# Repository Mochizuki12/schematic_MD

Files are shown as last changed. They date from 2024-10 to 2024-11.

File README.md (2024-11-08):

# schematic_MD
### 2chモータドライバのプロトタイプ<br>
[回路の仕様](https://github.com/Mochizuki12/schematic_MD/blob/v0.1.0/documents/MDdocument.pdf)<br>
[回路図](https://github.com/Mochizuki12/schematic_MD/blob/v0.1.0/documents/MD_schematics.pdf)<br>
[PCB](https://github.com/Mochizuki12/schematic_MD/blob/v0.1.0/documents/pcb.pdf)<br>

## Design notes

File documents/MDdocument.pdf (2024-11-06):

MDプロトタイプ１ | 1

# MDプロトタイプ１

最終版との差異
モータ用電源 13V~24V

ゲート電圧がモータ用電源電圧に依存

12V降圧レギュレータに変更。アクチュエータ側は最低13V必要

## 部品(IC)

部品名 | 型番 | 備考 | URL
ゲートドライバ | ADuM3224 | ADuM3223とピン 互換あり オーバーラップ保 護機能がないため 使用中止
ゲートドライバ | UCC21520DWR | オーバーラップ保 護あり ドライブ側の UVLOが高く (8V)、現状のコン デンサでは充電が 間に合わない可能 性あり プロトタイプで採 用 | https://jlcpcb.com/partdetail/TexasInstruments-UCC21520DWR/C601651 (https://jlcpcb.com/partdetail/TexasInstruments-UCC21520DWR/C601651)
ゲートドライバ | UCC21520ADWR | オーバーラップ保 護あり ドライブ側の UVLOが低い(5V)
マイコン | STM32F405 | ユニバーサルプロ グラムにより提供
CANトランシーバ | MAX3051 | | https://jlcpcb.com/partdetail/113237-MAX3051EKAT/C112005 (https://jlcpcb.com/partdetail/113237-MAX3051EKAT/C112005)
3端子レギュレータ | L78M05ABDT-TR | 5V降圧 | https://jlcpcb.com/partdetail/Stmicroelectronics-L78M05ABDTTR/C58069 (https://jlcpcb.com/partdetail/Stmicroelectronics-L78M05ABDTTR/C58069)
3端子レギュレータ | XC6206P332MR-G | 3.3V降圧 | https://jlcpcb.com/partdetail/TorexSemicon-XC6206P332MRG/C5446 (https://jlcpcb.com/partdetail/TorexSemicon-XC6206P332MRG/C5446)
3端子レギュレータ | NJM2396 | 12V降圧 | https://akizukidenshi.com/catalog/g/g109264/
ロジックIC | 74HC04D | NOTゲート | https://jlcpcb.com/partdetail/Nexperia-74HC04D653/C5590 (https://jlcpcb.com/partdetail/Nexperia-74HC04D653/C5590)

### 部品(受動部品)

部品名 | 型番 | 備考 | URL

ゲート抵抗10Ω | 選定基準は下記 に記載 | https://jlcpcb.com/partdetail/18103-0805W8F100JT5E/C17415 (https://jlcpcb.com/partdetail/18103-0805W8F100JT5E/C17415)
ブートストラッ プ抵抗100mΩ | | https://jlcpcb.com/partdetail/26077-1206W4F100LT5E/C25334 (https://jlcpcb.com/partdetail/26077-1206W4F100LT5E/C25334)
120Ω抵抗 | CAN 終端抵抗 | https://jlcpcb.com/partdetail/23514-0603WAF1200T5E/C22787 (https://jlcpcb.com/partdetail/23514-0603WAF1200T5E/C22787)
330Ω抵抗 | LED用 | https://jlcpcb.com/partdetail/23865-0603WAF3300T5E/C23138 (https://jlcpcb.com/partdetail/23865-0603WAF3300T5E/C23138)
680Ω抵抗 | LED用 | https://jlcpcb.com/partdetail/23955-0603WAF6800T5E/C23228 (https://jlcpcb.com/partdetail/23955-0603WAF6800T5E/C23228)
2kΩ抵抗 | LED用 | https://jlcpcb.com/partdetail/23702-0603WAF2001T5E/C22975 (https://jlcpcb.com/partdetail/23702-0603WAF2001T5E/C22975)
3.6kΩ抵抗 | LED用 | https://jlcpcb.com/partdetail/23707-0603WAF3601T5E/C22980 (https://jlcpcb.com/partdetail/23707-0603WAF3601T5E/C22980)
電力消費用10k 抵抗 | コンデンサの電 荷抜き | https://jlcpcb.com/partdetail/18590-1206W4F1002T5E/C17902 (https://jlcpcb.com/partdetail/18590-1206W4F1002T5E/C17902)
プルダウン用 10k抵抗 | | https://jlcpcb.com/partdetail/26487-0402WGF1002TCE/C25744 (https://jlcpcb.com/partdetail/26487-0402WGF1002TCE/C25744)
プルダウン用 20k抵抗 | | https://jlcpcb.com/partdetail/26508-0402WGF2002TCE/C25765 (https://jlcpcb.com/partdetail/26508-0402WGF2002TCE/C25765)
インジケータ LED Vf=1.7@5mA | 赤色 | https://jlcpcb.com/partdetail/Hubei_KentoElec-KT0603R/C2286 (https://jlcpcb.com/partdetail/Hubei_KentoElec-KT0603R/C2286)
インジケータ LED Vf=1.875@5mA | 黄色 | https://jlcpcb.com/partdetail/Hubei_KentoElec-KT0805Y/C2296 (https://jlcpcb.com/partdetail/Hubei_KentoElec-KT0805Y/C2296)
バイパス用コン デンサ0.1uF 12V, 5V系統 | | https://jlcpcb.com/partdetail/Yageo-CC0603KRX7R9BB104/C14663 (https://jlcpcb.com/partdetail/Yageo-CC0603KRX7R9BB104/C14663)
バイパス用コン デンサ0.1uF 3.3V系統 | | https://jlcpcb.com/partdetail/1877-CL05B104KO5NNNC/C1525 (https://jlcpcb.com/partdetail/1877-CL05B104KO5NNNC/C1525)
バイパス用コン デンサ4.7uF | | https://jlcpcb.com/partdetail/20375-CL10A475KO8NNNC/C19666 (https://jlcpcb.com/partdetail/20375-CL10A475KO8NNNC/C19666)
バイパス用コン デンサ2.2uF | | https://jlcpcb.com/partdetail/24366-CL10A225KO8NNNC/C23630 (https://jlcpcb.com/partdetail/24366-CL10A225KO8NNNC/C23630)
バイパス用コン デンサ1uF | | https://jlcpcb.com/partdetail/16531-CL10A105KB8NNNC/C15849 (https://jlcpcb.com/partdetail/16531-CL10A105KB8NNNC/C15849)
バイパス用コン デンサ1nF | | https://jlcpcb.com/partdetail/1940-CL10B102KB8NNNC/C1588 (https://jlcpcb.com/partdetail/1875-0402B102K500NT/C1523)
バイパス用コン デンサ22nF | | https://jlcpcb.com/partdetail/1884-0402B223K500NT/C1532 (https://jlcpcb.com/partdetail/1884-0402B223K500NT/C1532)
バイパス用コン デンサ0.47uF | | https://jlcpcb.com/partdetail/14623-CL21B474KBFNNNE/C13967 (https://jlcpcb.com/partdetail/14623-CL21B474KBFNNNE/C13967)
フェライトビー ズ 600Ω@100MHz | STM32アナログ 電源フィルタ用 | https://jlcpcb.com/partdetail/Sunlord-GZ2012D601TF/C1017 (https://jlcpcb.com/partdetail/Sunlord-GZ2012D601TF/C1017)

ショットキーバ リアダイオード | 超低IRタイプ Extend品 | https://jlcpcb.com/partdetail/RohmSemicon-RB168MM60TR/C509937 (https://jlcpcb.com/partdetail/RohmSemicon-RB168MM60TR/C509937)
Nch MOSFET | 標準アセンブリ 品 | https://jlcpcb.com/partdetail/VishayIntertech-SQJ886EPT1_GE3/C727822 (https://jlcpcb.com/partdetail/VishayIntertech-SQJ886EPT1_GE3/C727822)
Nch MOSFET | Economyでも可 能 Extend品 | https://jlcpcb.com/partdetail/VishayIntertech-SIR182DP_T1RE3/C467943 (https://jlcpcb.com/partdetail/VishayIntertech-SIR182DP_T1RE3/C467943)
ゲートキャパシ タ10uF | Extend品 | https://jlcpcb.com/partdetail/-12103C106K4T2A/C597571
フィルタ用抵抗 51Ω | PWM入力ロー パスフィルタを 構成 | https://jlcpcb.com/partdetail/23924-0603WAF510JT5E/C23197 (https://jlcpcb.com/partdetail/23924-0603WAF510JT5E/C23197)
フィルタ用コン デンサ33pF | PWM入力ロー パスフィルタを 構成 | https://jlcpcb.com/partdetail/2015-CL10C330JB8NNNC/C1663 (https://jlcpcb.com/partdetail/2015-CL10C330JB8NNNC/C1663)
LSE用水晶振動 子32.768kHz | STM用 | https://jlcpcb.com/partdetail/SeikoEpson-Q13FC13500004/C32346 (https://jlcpcb.com/partdetail/SeikoEpson-Q13FC13500004/C32346)
LSE用負荷容量 20pF | 32kHz水晶振動 子用 | https://jlcpcb.com/partdetail/1906-0402CG200J500NT/C1554 (https://jlcpcb.com/partdetail/1906-0402CG200J500NT/C1554)
HSE用水晶振動 子25MHz | STM用 | https://jlcpcb.com/partdetail/Yxc_CrystalOscillators-X322516MLB4SI/C13738 (https://jlcpcb.com/partdetail/Yxc_CrystalOscillators-X322525MOB4SI/C9006)
HSE用負荷容量 18pF | 25MHz用 | https://jlcpcb.com/partdetail/1999-CL10C180JB8NNNC/C1647 (https://jlcpcb.com/partdetail/1901-0402CG180J500NT/C1549)
リセットスイッ チ | 試験運用 | https://jlcpcb.com/partdetail/XkbConnection-TS_1187A_B_AB/C318884 (https://jlcpcb.com/partdetail/XkbConnection-TS_1187A_B_AB/C318884)
DIP スイッチ 4P | 秋月で購入 | https://akizukidenshi.com/catalog/g/g108929/

### 秋月購入品

部品名 | URL
ゲート電源用12V降圧 | https://akizukidenshi.com/catalog/g/g116614
バイパスコンデンサ22uF | https://akizukidenshi.com/catalog/g/g117899/
12V電源用電解コンデンサ | https://akizukidenshi.com/catalog/g/g102724/
5V, 3.3V電源用電解コンデンサ | https://akizukidenshi.com/catalog/g/g117887/
バルクコンデンサ | https://akizukidenshi.com/catalog/g/g116867/
DIP スイッチ 4P | https://akizukidenshi.com/catalog/g/g108929/
ピンヘッダ 2P | https://akizukidenshi.com/catalog/g/g108593/
ピンヘッダ 4P | https://akizukidenshi.com/catalog/g/g104392/
モータ電源入力用 XT60 M | https://akizukidenshi.com/catalog/g/g117953/
モータ接続用 XT60 F | https://akizukidenshi.com/catalog/g/g117952/
ジャンパ | https://akizukidenshi.com/catalog/g/g103687/

### その他

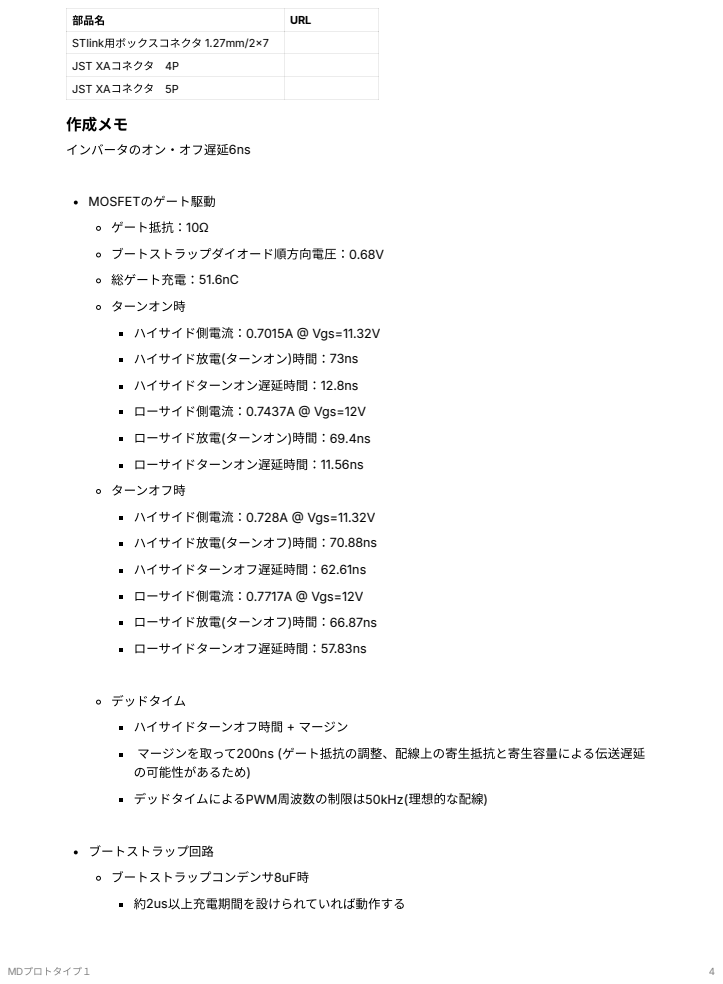
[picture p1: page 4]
作成メモ; インバータのオン・; オフ遅延6ns; MOSFETのゲート駆動; ゲート抵抗：10Ω; ブートストラップダイオード順方向電圧：0.68V; 総ゲート充電：51.6nC; ターンオン時; ハイサイド側電流：0.7015A @ Vgs=11.32V; ハイサイドターンオン遅延時間：12.8ns; ローサイド側電流：0.7437A @ Vgs=12V; ローサイドターンオン遅延時間：11.56ns; ターンオフ時; ハイサイド側電流：0.728A @ Vgs=11.32V; ハイサイドターンオフ遅延時間：62.61ns; ローサイド側電流：0.7717A @ Vgs=12V; ローサイドターンオフ遅延時間：57.83ns; デッドタイム; ハイサイドターンオフ時間 + マージン; マージンを取って200ns (ゲート抵抗の調整、配線上の寄生抵抗と寄生容量による伝送遅延; の可能性があるため); デッドタイムによるPWM周波数の制限は50kHz(理想的な配線); ブートストラップ回路; ブートストラップコンデンサ8uF時; 約2us以上充電期間を設けられていれば動作する

部品名 | URL
STlink用ボックスコネクタ 1.27mm/2×7
JST XAコネクタ 4P
JST XAコネクタ 5P

ハイサイド放電(ターンオン)時間：73ns

ローサイド放電(ターンオン)時間：69.4ns

ハイサイド放電(ターンオフ)時間：70.88ns

ローサイド放電(ターンオフ)時間：66.87ns

# プロトタイプ発注

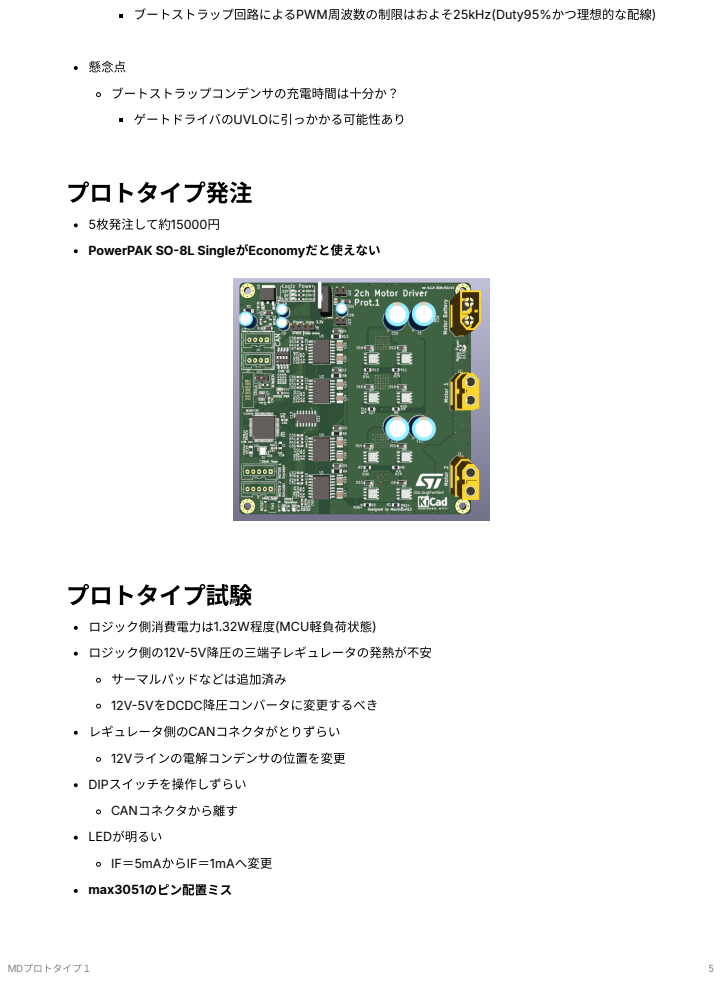
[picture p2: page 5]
ブートストラップ回路によるPWM周波数の制限はおよそ25kHz(Duty95%かつ理想的な配線); 懸念点; ブートストラップコンデンサの充電時間は十分か？; ゲートドライバのUVLOに引っかかる可能性あり; プロトタイプ試験; ロジック側消費電力は1.32W程度(MCU軽負荷状態); ロジック側の12V-5V降圧の三端子レギュレータの発熱が不安; サーマルパッドなどは追加済み; 12V-5VをDCDC降圧コンバータに変更するべき; レギュレータ側のCANコネクタがとりずらい; 12Vラインの電解コンデンサの位置を変更; DIPスイッチを操作しずらい; CANコネクタから離す; LEDが明るい; IF＝5mAからIF＝1mAへ変更; max3051のピン配置ミス

5枚発注して約15000円
PowerPAK SO-8L SingleがEconomyだと使えない

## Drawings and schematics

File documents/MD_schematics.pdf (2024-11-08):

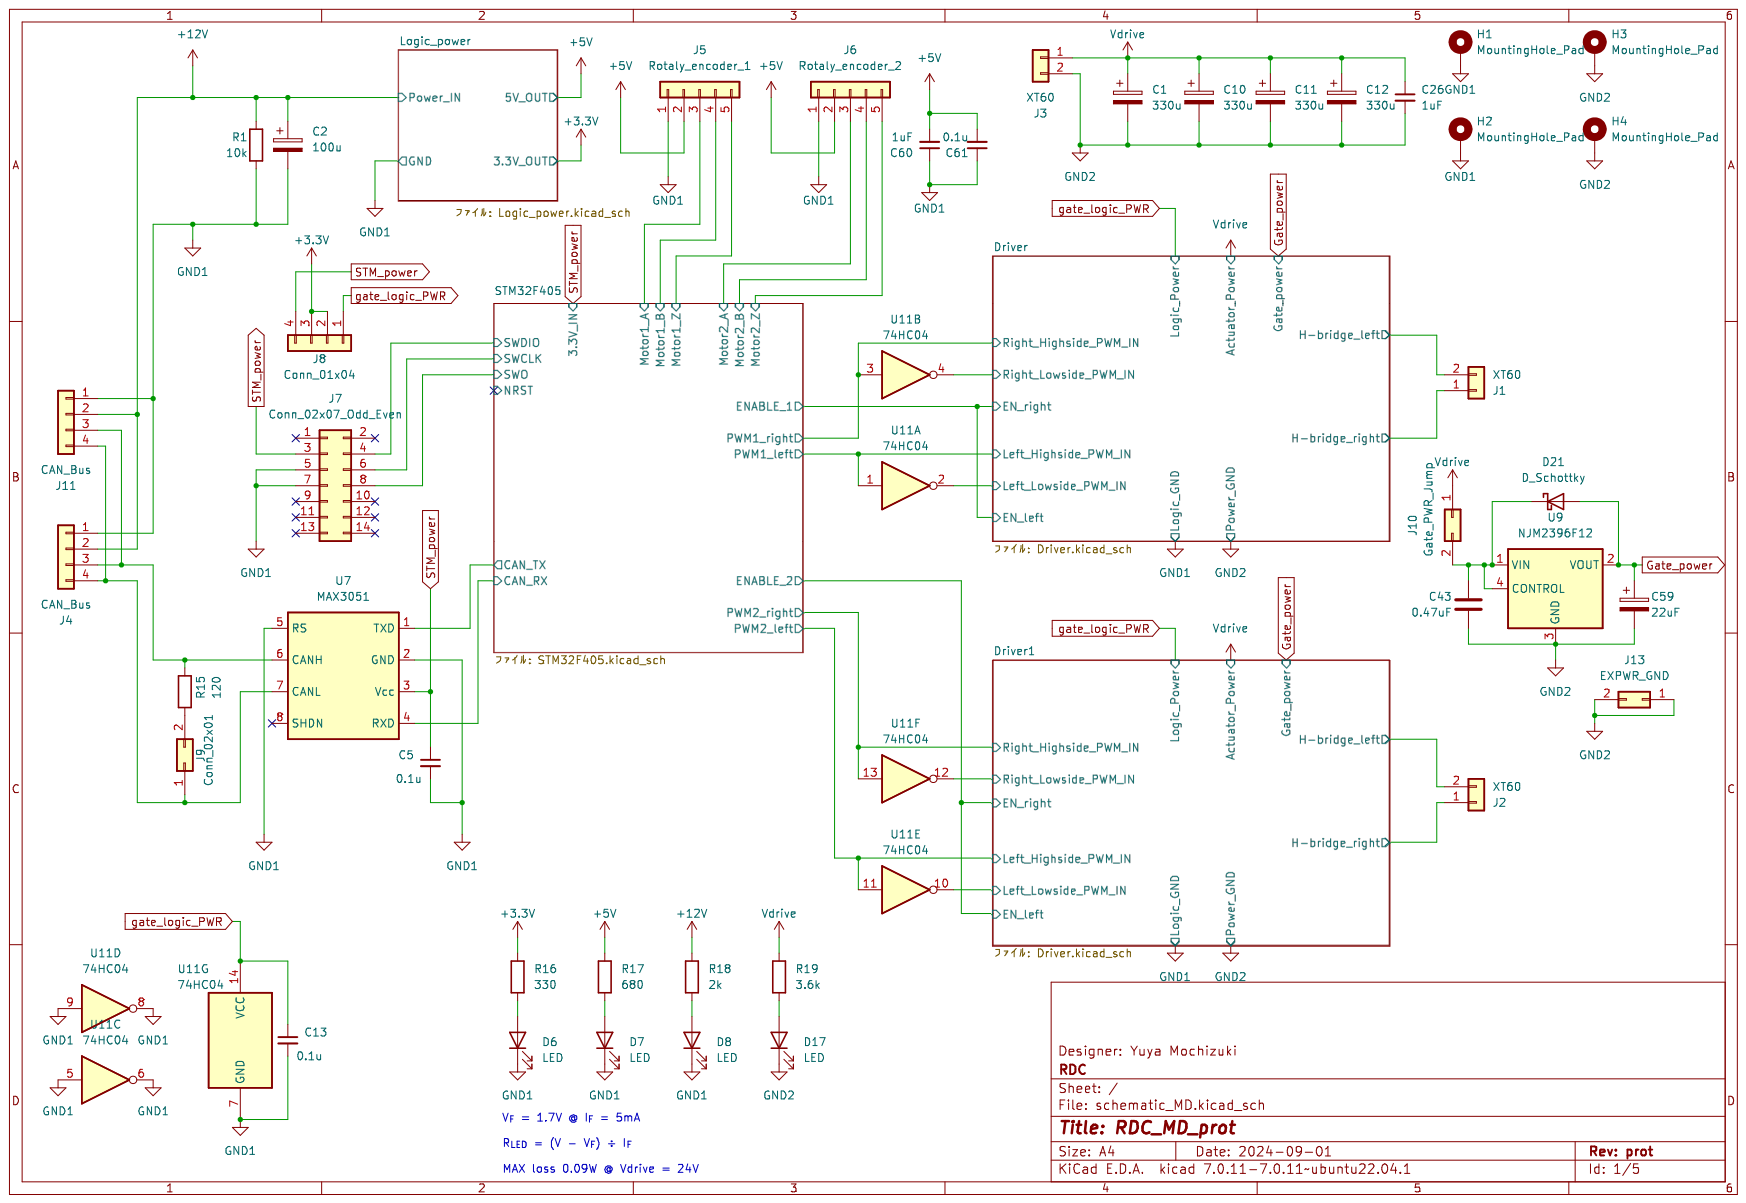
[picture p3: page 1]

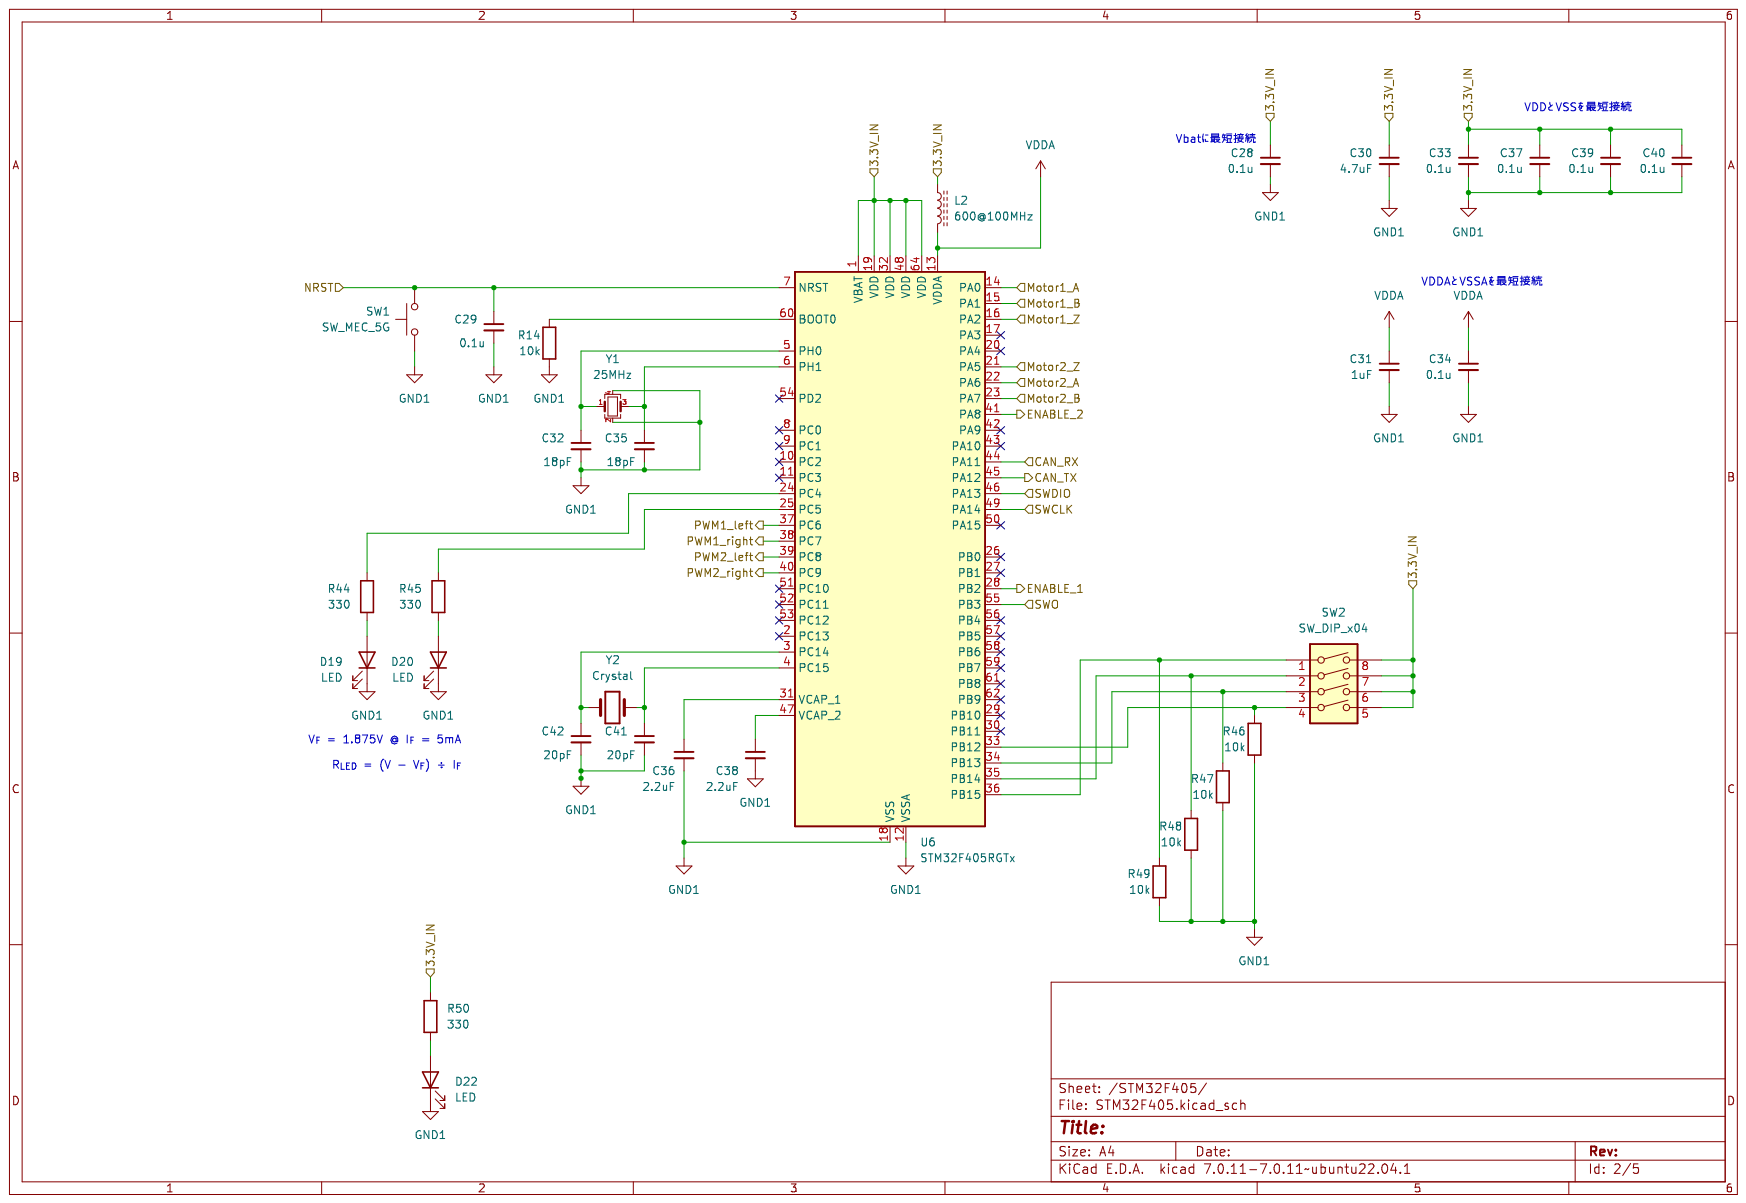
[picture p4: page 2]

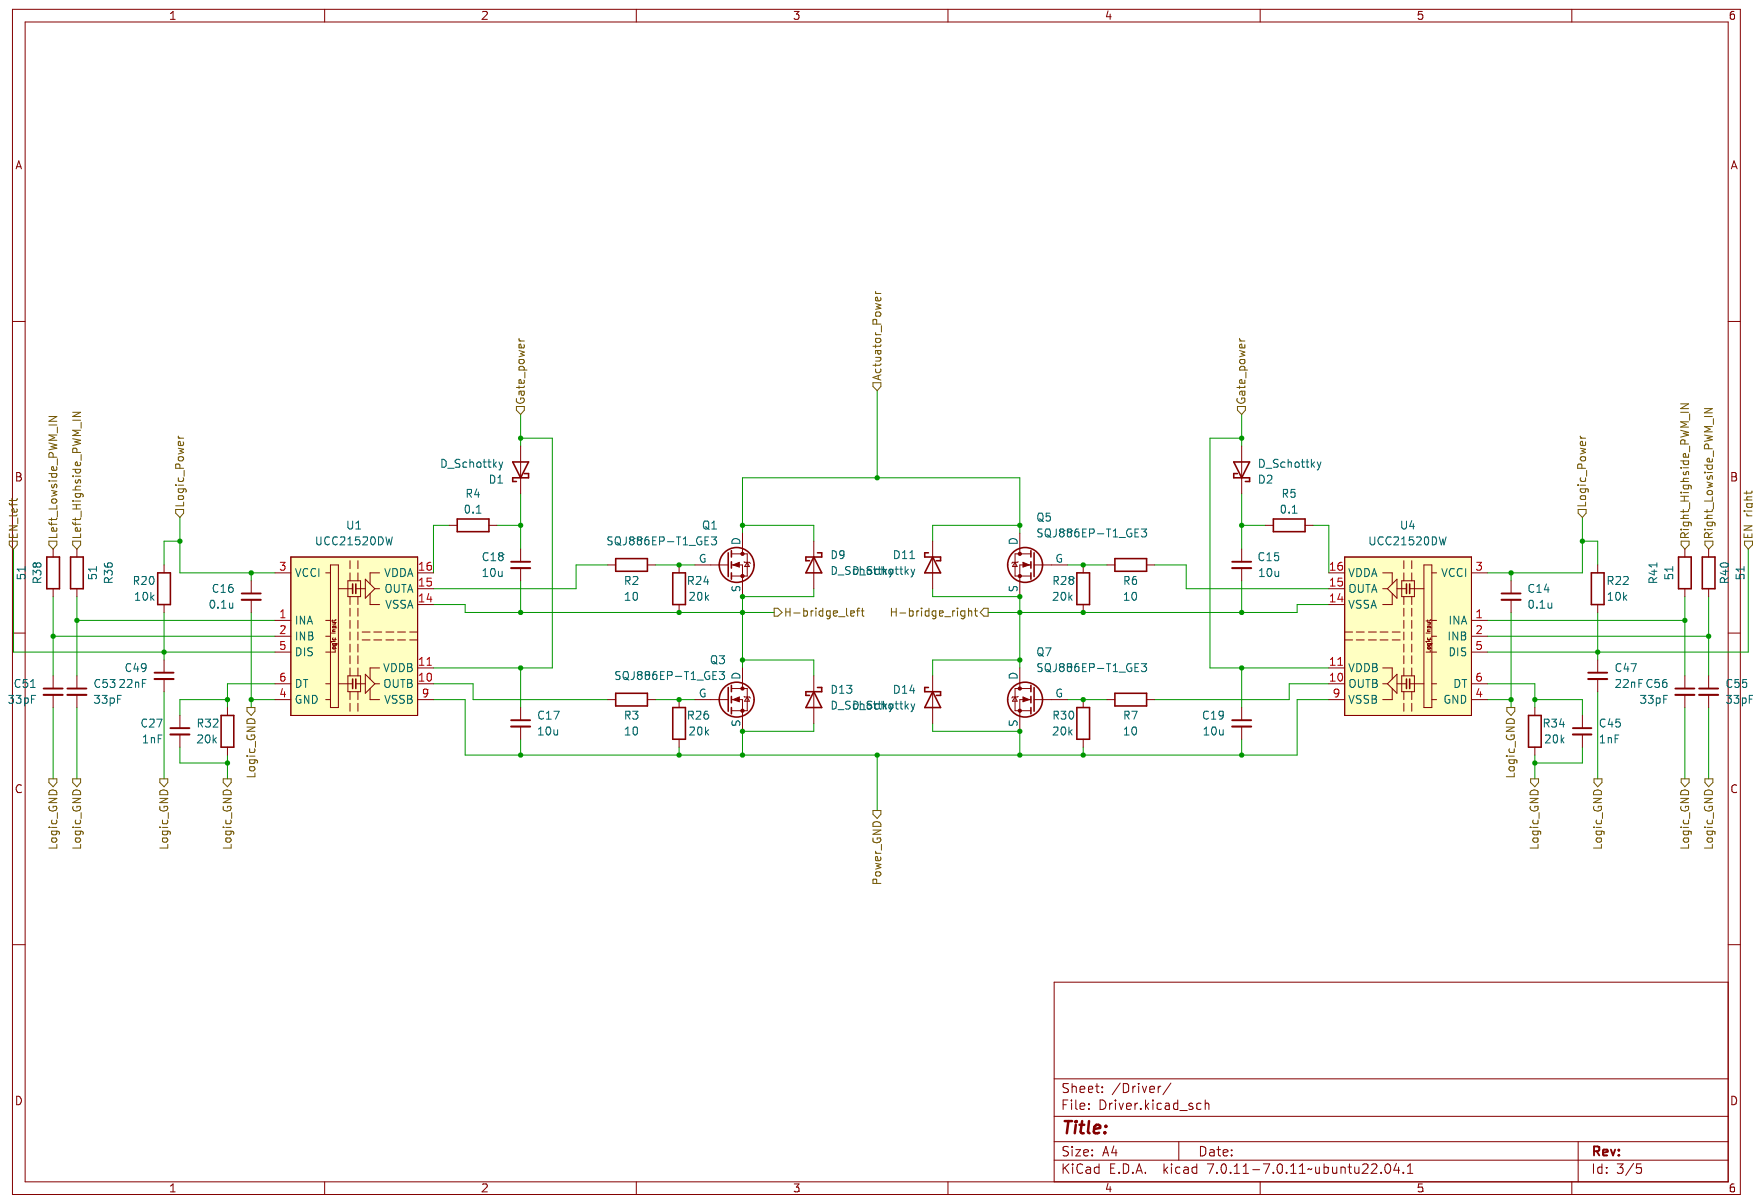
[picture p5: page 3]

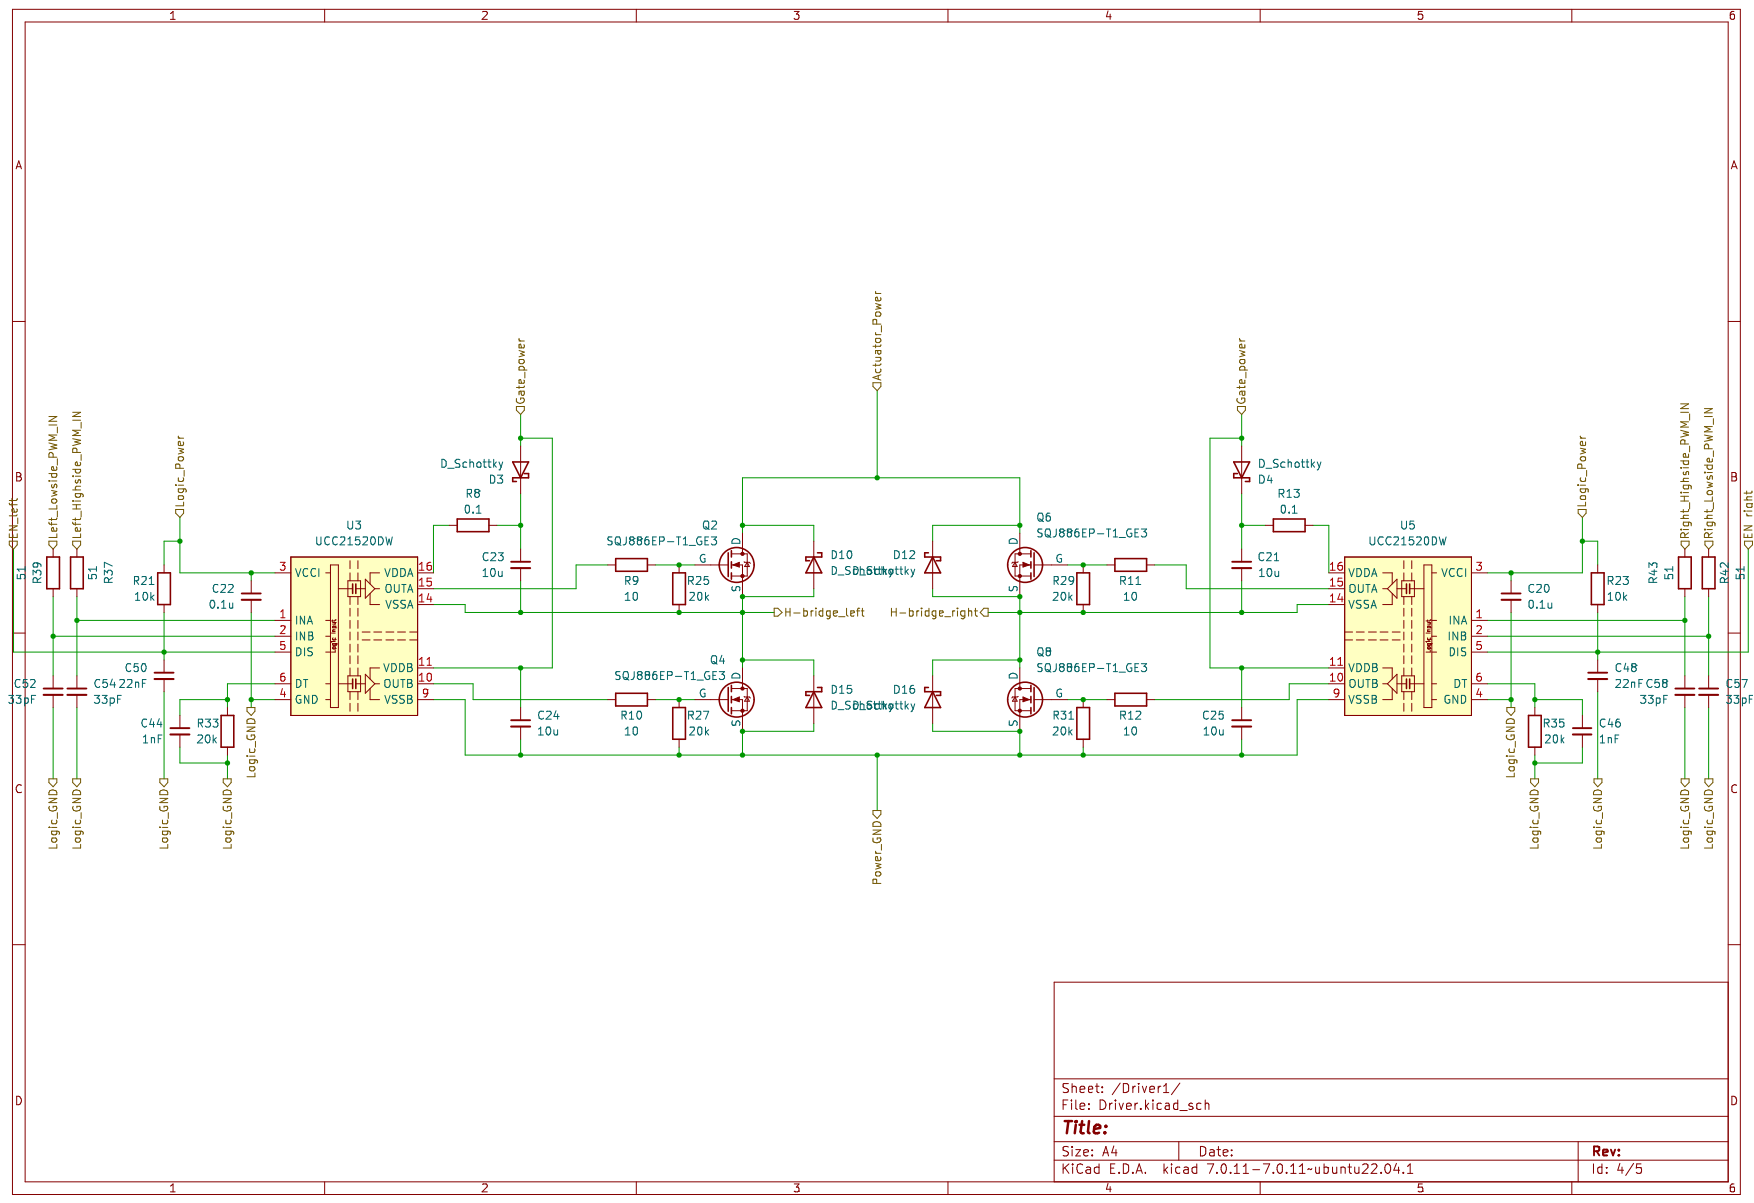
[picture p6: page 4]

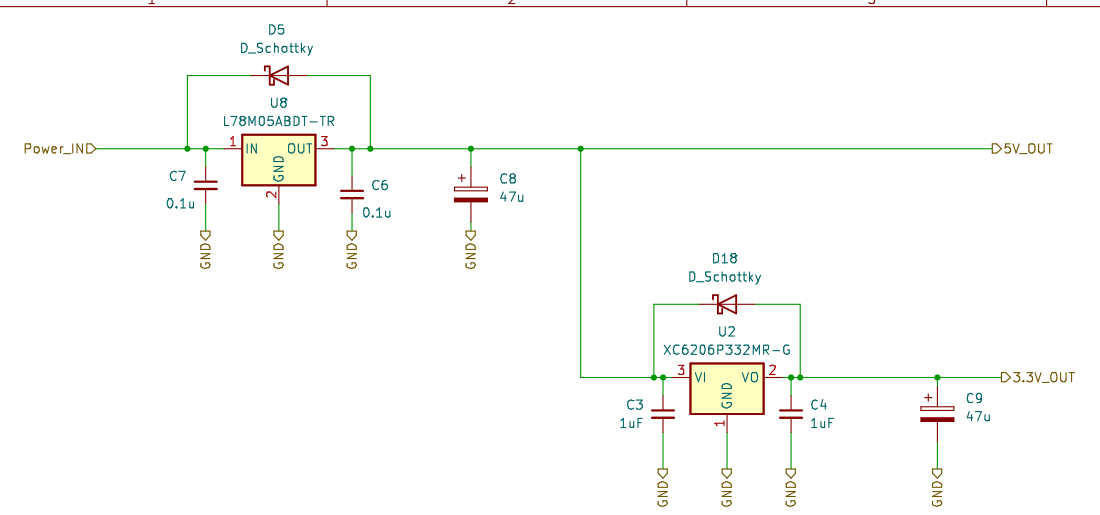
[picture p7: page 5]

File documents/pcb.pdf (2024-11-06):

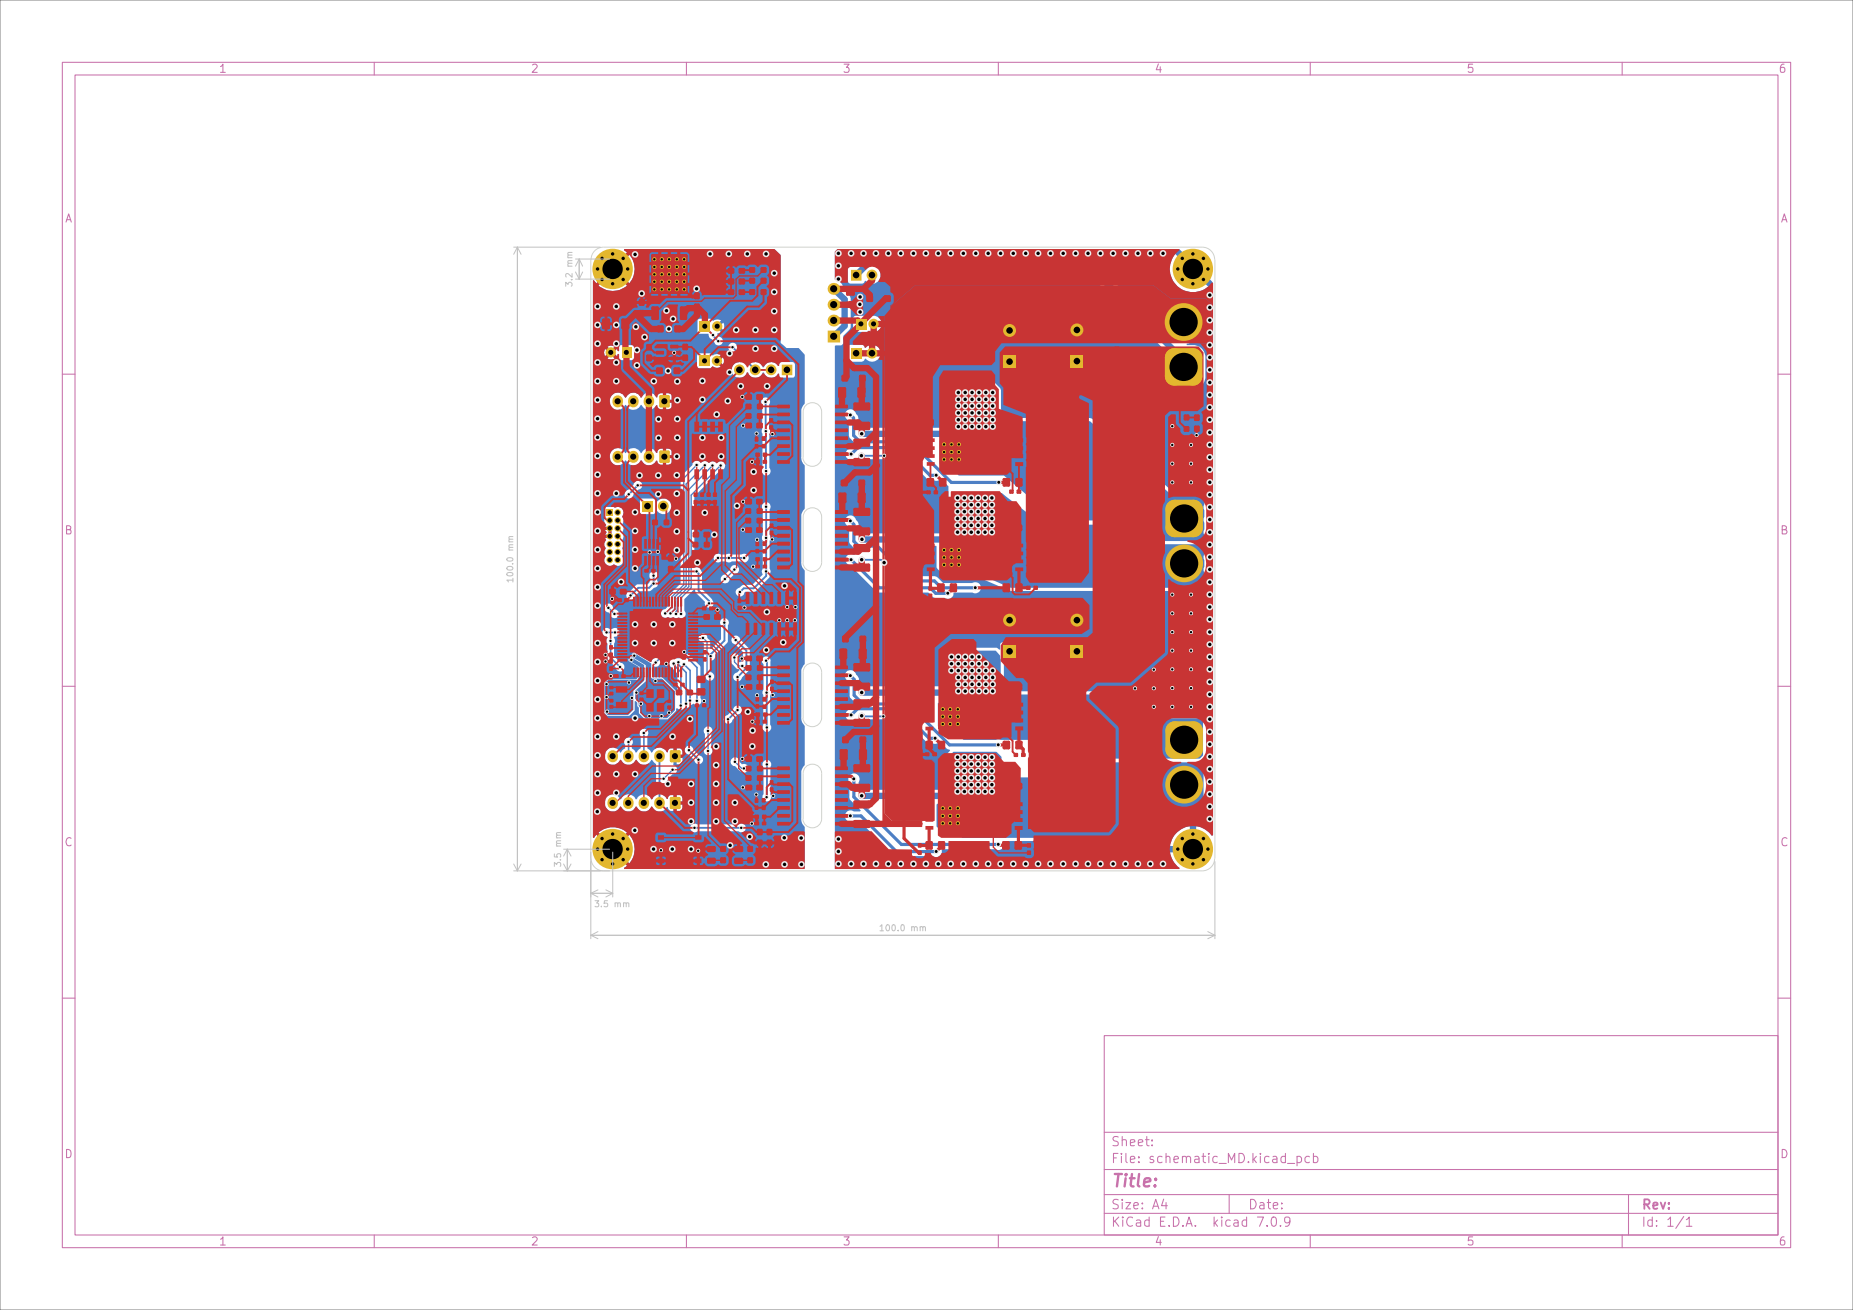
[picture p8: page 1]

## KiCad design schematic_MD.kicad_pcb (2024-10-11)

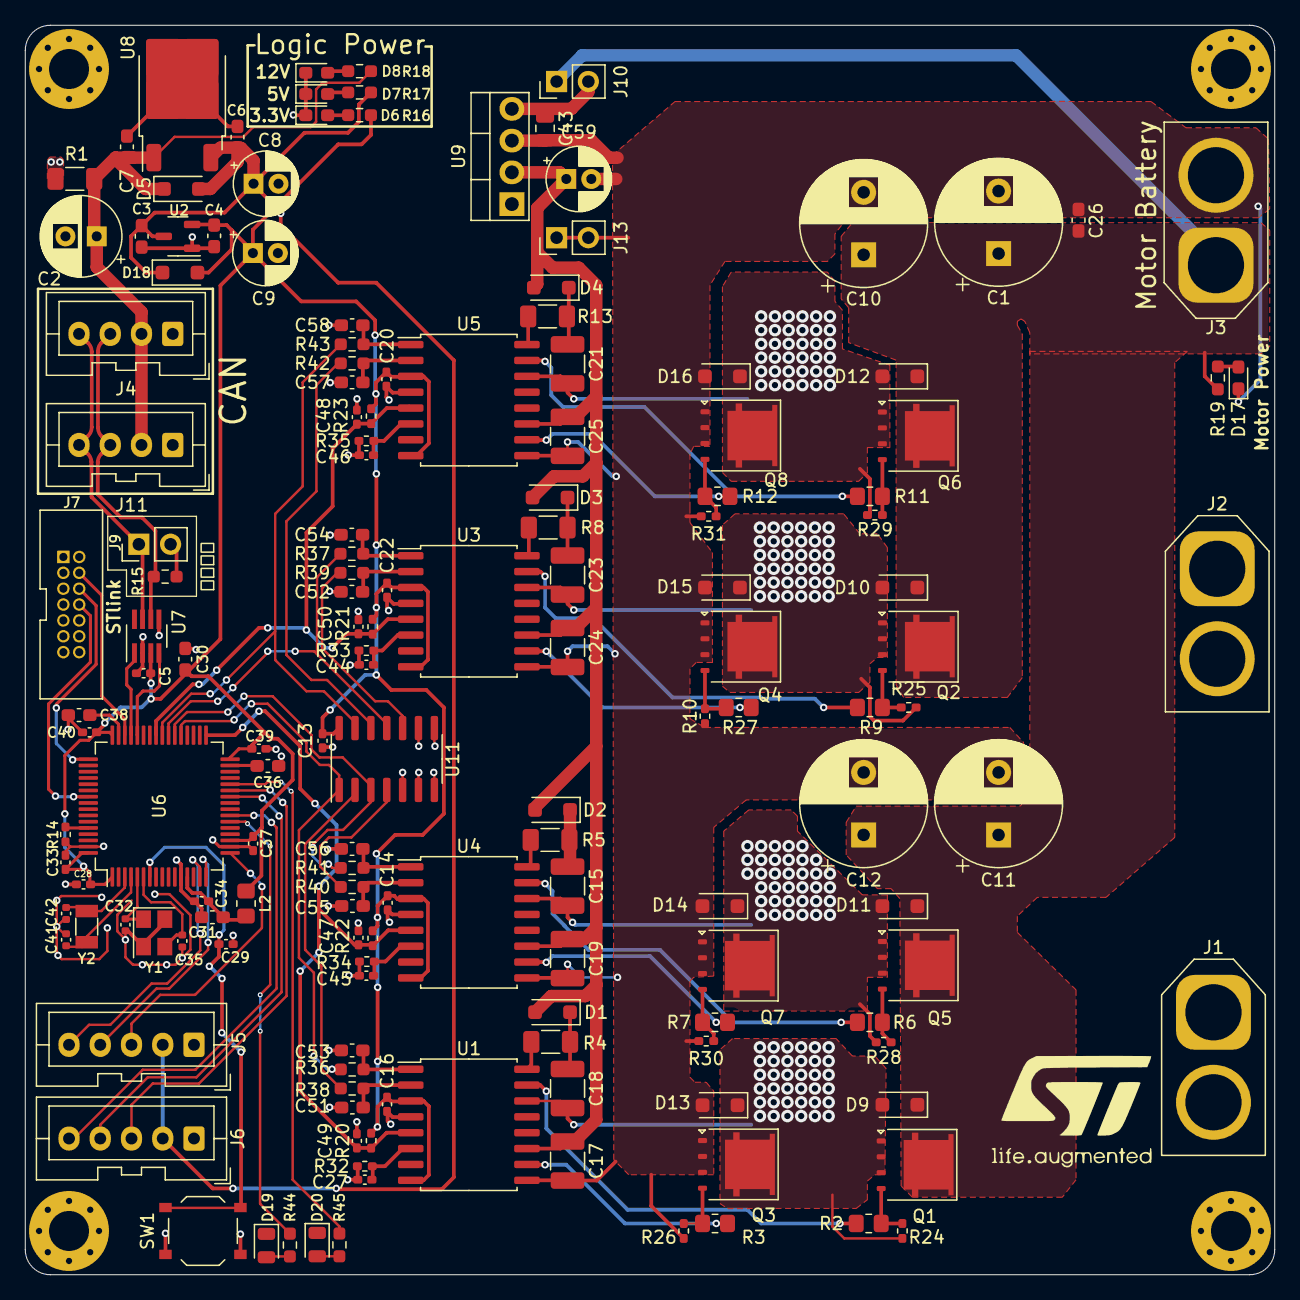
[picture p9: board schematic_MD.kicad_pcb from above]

Board: 2 copper layers, 100.0 x 100.0 mm, 161 parts (0 on the bottom side), 89 nets.

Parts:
C1, C10, C11, C12: 330u; CP_Radial_D10.0mm_P5.00mm
C2: 100u; CP_Radial_D6.3mm_P2.50mm
C3, C4, C26, C31: 1uF; C_0603_1608Metric_Pad1.08x0.95mm_HandSolder
C5, C13, C14, C16, C20, C22, C28, C29, C33, C34, C37, C39, C40: 0.1u; C_0402_1005Metric_Pad0.74x0.62mm_HandSolder
C6, C7: 0.1u; C_0603_1608Metric_Pad1.08x0.95mm_HandSolder
C8, C9: 47u; CP_Radial_D5.0mm_P2.00mm
C15, C17, C18, C19, C21, C23, C24, C25: 10u; C_1210_3225Metric_Pad1.33x2.70mm_HandSolder
C27, C44, C45, C46: 1nF; C_0402_1005Metric_Pad0.74x0.62mm_HandSolder
C30: 4.7uF; C_0603_1608Metric_Pad1.08x0.95mm_HandSolder
C32, C35: 18pF; C_0402_1005Metric
C36, C38: 2.2uF; C_0603_1608Metric_Pad1.08x0.95mm_HandSolder
C41, C42: 20pF; C_0402_1005Metric
C43: 0.47uF; C_0805_2012Metric
C47, C48, C49, C50: 22nF; C_0402_1005Metric_Pad0.74x0.62mm_HandSolder
C51, C52, C53, C54, C55, C56, C57, C58: 33pF; C_0603_1608Metric_Pad1.08x0.95mm_HandSolder
C59: 22uF; CP_Radial_D5.0mm_P2.00mm
D1, D2, D3, D4, D5, D9, D10, D11, D12, D13, D14, D15, D16, D18: D_Schottky; D_SOD-123F
D6, D7, D8, D17: LED; LED_0603_1608Metric_Pad1.05x0.95mm_HandSolder
D19, D20: LED; LED_0805_2012Metric
H1, H2, H3, H4: MountingHole_Pad; MountingHole_3.2mm_M3_Pad_Via
J1, J2: XT60; AMASS_XT60-F_1x02_P7.20mm_Vertical
J3: XT60; AMASS_XT60-M_1x02_P7.20mm_Vertical
J4, J11: CAN_Bus; JST_XA_B04B-XASK-1_1x04_P2.50mm_Vertical
J5: Rotaly_encoder_1; JST_XA_B05B-XASK-1_1x05_P2.50mm_Vertical
J6: Rotaly_encoder_2; JST_XA_B05B-XASK-1_1x05_P2.50mm_Vertical
J7: Conn_02x07_Odd_Even; JTAG_box_connector
J9: Conn_02x01; PinHeader_1x02_P2.54mm_Vertical
J10: Gate_PWR_Jump; PinHeader_1x02_P2.54mm_Vertical
J13: EXPWR_GND; PinHeader_1x02_P2.54mm_Vertical
L2: 600@100MHz; R_0805_2012Metric_Pad1.20x1.40mm_HandSolder
Q1, Q2, Q3, Q4, Q5, Q6, Q7, Q8: SQJ886EP-T1_GE3; PowerPAK_SO-8L_Single
R1: 10k; R_1206_3216Metric_Pad1.30x1.75mm_HandSolder
R2, R3, R6, R7, R9, R10, R11, R12: 10; R_0805_2012Metric_Pad1.20x1.40mm_HandSolder
R4, R5, R8, R13: 0.1; R_1206_3216Metric_Pad1.30x1.75mm_HandSolder
R14, R20, R21, R22, R23: 10k; R_0402_1005Metric_Pad0.72x0.64mm_HandSolder
R15: 120; R_0603_1608Metric_Pad0.98x0.95mm_HandSolder
R16, R44, R45: 330; R_0603_1608Metric_Pad0.98x0.95mm_HandSolder
R17: 680; R_0603_1608Metric_Pad0.98x0.95mm_HandSolder
R18: 2k; R_0603_1608Metric_Pad0.98x0.95mm_HandSolder
R19: 3.6k; R_0603_1608Metric_Pad0.98x0.95mm_HandSolder
R24, R25, R26, R27, R28, R29, R30, R31, R32, R33, R34, R35: 20k; R_0402_1005Metric_Pad0.72x0.64mm_HandSolder
R36, R37, R38, R39, R40, R41, R42, R43: 51; R_0603_1608Metric_Pad0.98x0.95mm_HandSolder
SW1: SW_MEC_5G; SW_Push_1P1T_XKB_TS-1187A
U1, U3, U4, U5: UCC21520DW; SOIC-16W_7.5x10.3mm_P1.27mm
U2: XC6206P332MR-G; SOT-23-3
U6: STM32F405RGTx; LQFP-64_10x10mm_P0.5mm
U7: MAX3051; SOT-23-8_Handsoldering
U8: L78M05ABDT-TR; TO-252-2
U9: NJM2396F12; TO-220-4_Vertical
U11: 74HC04; SOIC-14_3.9x8.7mm_P1.27mm
Y1: 25MHz; Crystal_SMD_3225-4Pin_3.2x2.5mm
Y2: Crystal; Crystal_SMD_3215-2Pin_3.2x1.5mm

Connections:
+3.3V: C4.1, C5.1, C9.1, C13.1, C14.1, C16.1, C20.1, C22.1, C28.1, C30.1, C33.1, C37.1, C39.1, C40.1, D18.2 (A), L2.1, R16.1, R20.1, R21.1, R22.1, R23.1, U1.3 (VCCI), U1.8 (VCCI), U2.2 (VO), U3.3 (VCCI), U3.8 (VCCI), U4.3 (VCCI), U4.8 (VCCI), U5.3 (VCCI), U5.8 (VCCI), U6.1 (VBAT), U6.19 (VDD), U6.32 (VDD), U6.48 (VDD), U6.64 (VDD), U7.3 (Vcc), U11.14 (VCC)
+5V: C3.1, C6.1, C8.1, D5.2 (A), D18.1 (K), J5.2, J6.2, R17.1, U2.3 (VI), U8.3 (OUT)
+12V: C2.1, C7.1, D5.1 (K), J4.2, J11.2, R1.1, R18.1, U8.1 (IN)
/Driver1/EN_left: C48.1, C50.1, R21.2, R23.2, U3.5 (DIS), U5.5 (DIS), U6.41 (PA8)
/Driver1/H-bridge_left: C23.2, D10.2 (A), D15.1 (K), J2.2, Q2.1 (S), Q2.2 (S), Q2.3 (S), Q4.5 (D), R25.2, U3.14 (VSSA)
/Driver1/H-bridge_right: C21.2, D12.2 (A), D16.1 (K), J2.1, Q6.1 (S), Q6.2 (S), Q6.3 (S), Q8.5 (D), R29.2, U5.14 (VSSA)
/Driver1/Left_Highside_PWM_IN: R37.1, U6.39 (PC8), U11.11
/Driver1/Left_Lowside_PWM_IN: R39.1, U11.10
/Driver1/Right_Highside_PWM_IN: R43.1, U6.40 (PC9), U11.13
/Driver1/Right_Lowside_PWM_IN: R42.1, U11.12
/Driver/EN_left: C47.1, C49.1, R20.2, R22.2, U1.5 (DIS), U4.5 (DIS), U6.33 (PB12)
/Driver/H-bridge_left: C18.2, D9.2 (A), D13.1 (K), J1.2, Q1.1 (S), Q1.2 (S), Q1.3 (S), Q3.5 (D), R24.2, U1.14 (VSSA)
/Driver/H-bridge_right: C15.2, D11.2 (A), D14.1 (K), J1.1, Q5.1 (S), Q5.2 (S), Q5.3 (S), Q7.5 (D), R28.2, U4.14 (VSSA)
/Driver/Left_Highside_PWM_IN: R36.1, U6.37 (PC6), U11.1
/Driver/Left_Lowside_PWM_IN: R38.1, U11.2
/Driver/Right_Highside_PWM_IN: R41.1, U6.38 (PC7), U11.3
/Driver/Right_Lowside_PWM_IN: R40.1, U11.4
/STM32F405/CAN_RX: U6.44 (PA11), U7.4 (RXD)
/STM32F405/CAN_TX: U6.45 (PA12), U7.1 (TXD)
/STM32F405/Motor1_A: J5.3, U6.17 (PA3)
/STM32F405/Motor1_B: J5.4, U6.16 (PA2)
/STM32F405/Motor1_Z: J5.5, U6.15 (PA1)
/STM32F405/Motor2_A: J6.3, U6.27 (PB1)
/STM32F405/Motor2_B: J6.4, U6.26 (PB0)
/STM32F405/Motor2_Z: J6.5, U6.23 (PA7)
/STM32F405/NRST: C29.1, J7.12, SW1.2 (B), U6.7 (NRST)
/STM32F405/SWCLK: J7.6, U6.49 (PA14)
/STM32F405/SWDIO: J7.4, U6.46 (PA13)
/STM32F405/SWO: J7.8, U6.55 (PB3)
GND1: C2.2, C3.2, C4.2, C5.2, C6.2, C7.2, C8.2, C9.2, C13.2, C14.2, C16.2, C20.2, C22.2, C27.2, C28.2, C29.2, C30.2, C31.2, C32.2, C33.2, C34.2, C35.2, C36.2, C37.2, C38.2, C39.2, C40.2, C41.2, C42.2, C44.2, C45.2, C46.2, C47.2, C48.2, C49.2, C50.2, C51.2, C52.2, C53.2, C54.2, C55.2, C56.2, C57.2, C58.2, D6.1 (K), D7.1 (K), D8.1 (K), D19.1 (K), D20.1 (K), H1.1, H2.1, J4.1, J5.1, J6.1, J7.5, J7.7, J11.1, R1.2, R14.2, R32.2, R33.2, R34.2, R35.2, SW1.1 (A), U1.4 (GND), U2.1 (GND), U3.4 (GND), U4.4 (GND), U5.4 (GND), U6.12 (VSSA), U6.18 (VSS), U6.63 (VSS), U7.2 (GND), U7.5 (RS), U8.2 (GND), U11.5, U11.6, U11.7 (GND), U11.8, U11.9, Y1.2, Y1.4
GND2: C1.2, C10.2, C11.2, C12.2, C17.2, C19.2, C24.2, C25.2, C26.2, C43.2, C59.2, D13.2 (A), D14.2 (A), D15.2 (A), D16.2 (A), D17.1 (K), H3.1, H4.1, J3.2, J13.1, J13.2, Q3.1 (S), Q3.2 (S), Q3.3 (S), Q4.1 (S), Q4.2 (S), Q4.3 (S), Q7.1 (S), Q7.2 (S), Q7.3 (S), Q8.1 (S), Q8.2 (S), Q8.3 (S), R26.2, R27.2, R30.2, R31.2, U1.9 (VSSB), U3.9 (VSSB), U4.9 (VSSB), U5.9 (VSSB), U9.3 (GND)
Gate_power: C17.1, C19.1, C24.1, C25.1, C59.1, D1.2 (A), D2.2 (A), D3.2 (A), D4.2 (A), U1.11 (VDDB), U3.11 (VDDB), U4.11 (VDDB), U5.11 (VDDB), U9.2 (VOUT)
unnamed: C18.1, D1.1 (K), R4.2
unnamed: C15.1, D2.1 (K), R5.2
unnamed: C23.1, D3.1 (K), R8.2
unnamed: C21.1, D4.1 (K), R13.2
unnamed: D6.2 (A), R16.2
unnamed: D7.2 (A), R17.2
unnamed: D8.2 (A), R18.2
unnamed: D17.2 (A), R19.2
unnamed: D19.2 (A), R44.2
unnamed: D20.2 (A), R45.2
unnamed: J9.2, R15.1
unnamed: C43.1, J10.2, U9.1 (VIN), U9.4 (CONTROL)
unnamed: J4.3, J11.3, R15.2, U7.6 (CANH)
unnamed: J4.4, J9.1, J11.4, U7.7 (CANL)
unnamed: Q1.4 (G), R2.2, R24.1
unnamed: Q2.4 (G), R9.2, R25.1
unnamed: Q3.4 (G), R3.2, R26.1
unnamed: Q4.4 (G), R10.2, R27.1
unnamed: Q5.4 (G), R6.2, R28.1
unnamed: Q6.4 (G), R11.2, R29.1
unnamed: Q7.4 (G), R7.2, R30.1
unnamed: Q8.4 (G), R12.2, R31.1
unnamed: C27.1, R32.1, U1.6 (DT)
unnamed: C53.1, R36.2, U1.1 (INA)
unnamed: C51.1, R38.2, U1.2 (INB)
unnamed: R2.1, U1.15 (OUTA)
unnamed: R3.1, U1.10 (OUTB)
unnamed: R4.1, U1.16 (VDDA)
unnamed: C44.1, R33.1, U3.6 (DT)
unnamed: C54.1, R37.2, U3.1 (INA)
unnamed: C52.1, R39.2, U3.2 (INB)
unnamed: R9.1, U3.15 (OUTA)
unnamed: R10.1, U3.10 (OUTB)
unnamed: R8.1, U3.16 (VDDA)
unnamed: C45.1, R34.1, U4.6 (DT)
unnamed: C56.1, R41.2, U4.1 (INA)
unnamed: C55.1, R40.2, U4.2 (INB)
unnamed: R6.1, U4.15 (OUTA)
unnamed: R7.1, U4.10 (OUTB)
unnamed: R5.1, U4.16 (VDDA)
unnamed: C46.1, R35.1, U5.6 (DT)
unnamed: C58.1, R43.2, U5.1 (INA)
unnamed: C57.1, R42.2, U5.2 (INB)
unnamed: R11.1, U5.15 (OUTA)
unnamed: R12.1, U5.10 (OUTB)
unnamed: R13.1, U5.16 (VDDA)
unnamed: R14.1, U6.60 (BOOT0)
unnamed: R44.1, U6.22 (PA6)
unnamed: R45.1, U6.28 (PB2)
unnamed: C42.1, U6.3 (PC14), Y2.1
unnamed: C41.1, U6.4 (PC15), Y2.2
unnamed: C32.1, U6.5 (PH0), Y1.1
unnamed: C35.1, U6.6 (PH1), Y1.3
unnamed: C36.1, U6.31 (VCAP_1)
unnamed: C38.1, U6.47 (VCAP_2)
VDDA: C31.1, C34.1, L2.2, U6.13 (VDDA)
Vdrive: C1.1, C10.1, C11.1, C12.1, C26.1, D9.1 (K), D10.1 (K), D11.1 (K), D12.1 (K), J3.1, J10.1, Q1.5 (D), Q2.5 (D), Q5.5 (D), Q6.5 (D), R19.1

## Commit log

2024-09-23 schematic update
    [Driver.kicad_sch, Logic_power.kicad_sch, STM32F405.kicad_sch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]
2024-09-25 update Driver circuit
    [Driver.kicad_sch, Logic_power.kicad_sch, STM32F405.kicad_sch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]
2024-09-27 update parts list
    [Driver.kicad_sch, STM32F405.kicad_sch, schematic_MD.kicad_sch]
2024-09-27 add footprint
    [Logic_power.kicad_sch, STM32F405.kicad_sch, schematic_MD.kicad_pcb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]
2024-09-28 pattern update
    [schematic_MD.kicad_pcb, schematic_MD.kicad_sch]
2024-10-01 Update motor driver circuit
    [Driver.kicad_sch, Logic_power.kicad_sch, STM32F405.kicad_sch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]
2024-10-01 Change gate driver
    [Driver.kicad_sch, schematic_MD.kicad_pcb, schematic_MD.kicad_sch]
2024-10-02 fix design
    [schematic_MD.kicad_pcb]
2024-10-03 add MOSFET pulldown
    [Driver.kicad_sch, Logic_power.kicad_sch, schematic_MD.kicad_pcb]
2024-10-05 fix powerline
    [schematic_MD.kicad_pcb]
2024-10-06 power line fix
    [schematic_MD.kicad_pcb]
2024-10-08 fix drive circuit
    [Driver.kicad_sch, schematic_MD.kicad_pcb, schematic_MD.kicad_sch]
2024-10-08 add logic parts
    [Driver.kicad_sch, STM32F405.kicad_sch, schematic_MD.kicad_pcb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]
2024-10-09 update pcb
    [STM32F405.kicad_sch, schematic_MD.kicad_pcb]
2024-10-09 fix logic
    [STM32F405.kicad_sch, schematic_MD.kicad_pcb, schematic_MD.kicad_sch]
2024-10-11 logic design update
    [STM32F405.kicad_sch, schematic_MD.kicad_pcb, schematic_MD.kicad_sch]
2024-10-11 precompleate PCB design
    [STM32F405.kicad_sch, schematic_MD.kicad_pcb, schematic_MD.kicad_sch]
2024-10-11 add gatedriver power
    [Driver.kicad_sch, Logic_power.kicad_sch, STM32F405.kicad_sch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]
2024-10-12 add silkprint & GND plane
    [STM32F405.kicad_sch, schematic_MD.kicad_sch]
2024-10-14 release prot.1 v0.1.0
    [Driver.kicad_sch, STM32F405.kicad_sch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]
